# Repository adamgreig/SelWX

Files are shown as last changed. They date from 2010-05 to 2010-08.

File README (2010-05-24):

SelWX

A weather station in Selwyn College, Cambridge, UK.

Reads weather data from a wind vane, anemometer, rain cup, light sensor,
relative humidity sensor, light sensor, temperature sensor and barometric
pressure sensor. Sends this data to a web application over ethernet and
the internet at large.

By Jon Sowman & Adam Greig
May 2010

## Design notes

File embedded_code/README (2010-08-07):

SelWX Embedded Code
This is the code that runs on the ARM in the weather station.

Build requirements are GCC for arm-none-eabi and libopenstm32;
the easiest way to obtain both is via summon-arm-toolchain:
http://github.com/esden/summon-arm-toolchain

Edit it to set LIBOPENSTM32_EN=1 and run, then make sure its resulting
directory (~/arm-none-eabi by default) is in your PATH.

Build with 'make'; 'make upload' will run stm32loader.py to flash the
resulting binary onto the STM32 via its serial bootloader.

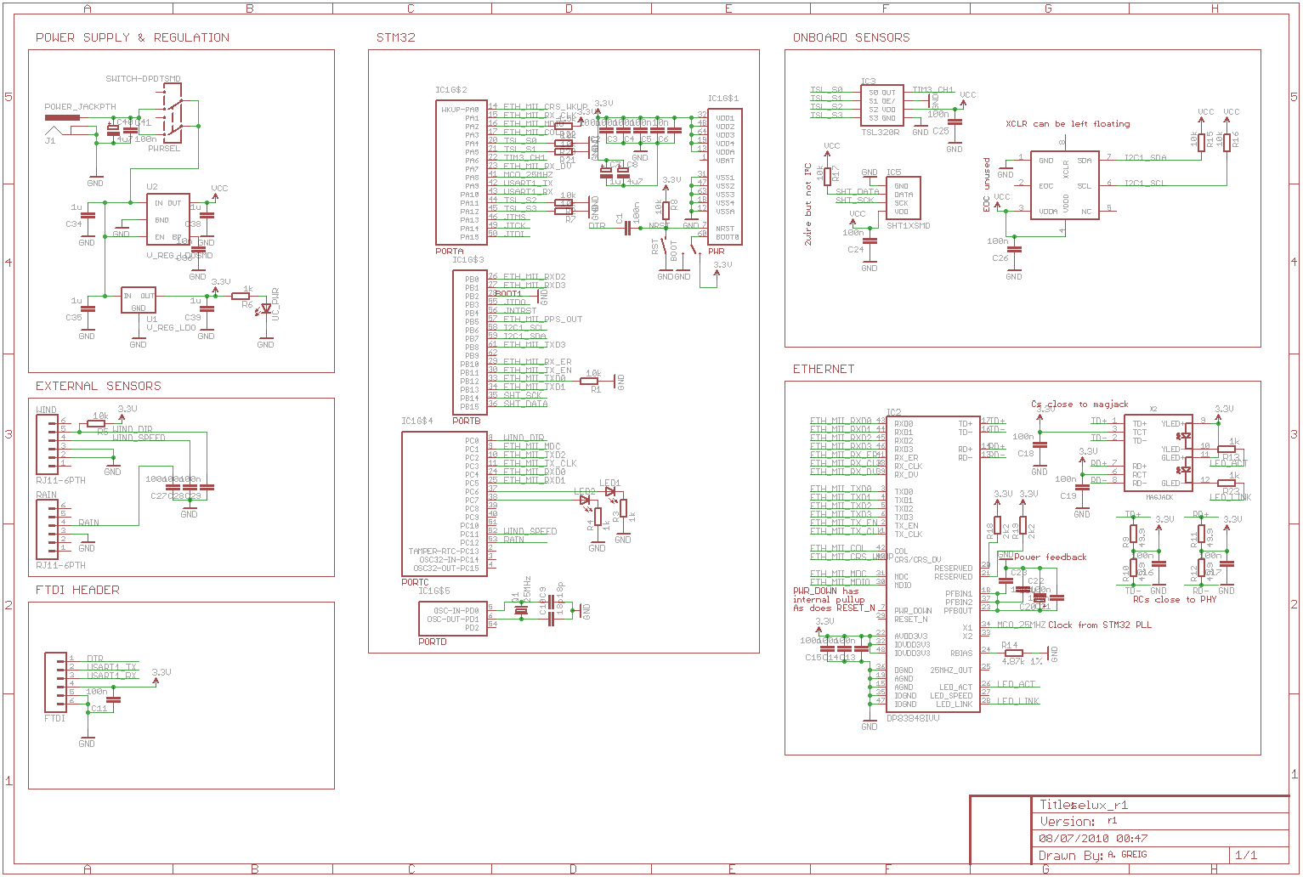
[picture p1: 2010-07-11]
pcb/selwx_r1/selwx_r1_schematic.png

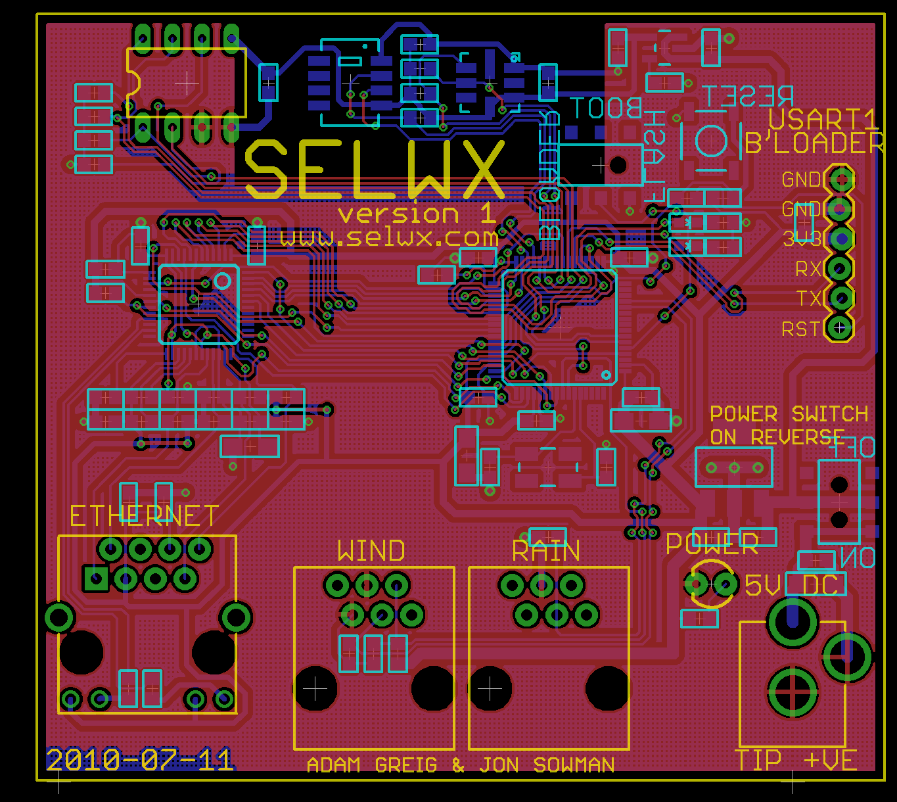
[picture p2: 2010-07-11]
pcb/selwx_r1/selwx_r1_board.png

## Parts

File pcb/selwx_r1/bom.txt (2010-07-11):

Partlist

Exported from selwx_r1.sch at 11/07/2010 18:55

EAGLE Version 5.10.0 Copyright (c) 1988-2010 CadSoft

Part     Value          Device                Package            Library     Sheet

BOOT                    SWITCH-SPSTSMD        AYZ0202            SparkFun    1
C1       100n           C-EUC0603             C0603              rcl         1
C2       100n           C-EUC0603             C0603              rcl         1
C3       100n           C-EUC0603             C0603              rcl         1
C4       100n           C-EUC0603             C0603              rcl         1
C5       100n           C-EUC0603             C0603              rcl         1
C6       10n            C-EUC0603             C0603              rcl         1
C7       1u             CPOL-EUSMCA           SMC_A              rcl         1
C8       4u7            CPOL-EUSMCA           SMC_A              rcl         1
C9       18p            C-EUC0603             C0603              rcl         1
C10      18p            C-EUC0603             C0603              rcl         1
C11      100n           C-EUC0603             C0603              rcl         1
C13      100n           C-EUC0603             C0603              rcl         1
C14      100n           C-EUC0603             C0603              rcl         1
C15      100n           C-EUC0603             C0603              rcl         1
C16      100n           C-EUC0603             C0603              rcl         1
C17      100n           C-EUC0603             C0603              rcl         1
C18      100n           C-EUC0603             C0603              rcl         1
C19      100n           C-EUC0603             C0603              rcl         1
C20      10u            CPOL-EUSMCA           SMC_A              rcl         1
C21      100n           C-EUC0603             C0603              rcl         1
C22      100n           C-EUC0603             C0603              rcl         1
C23      100n           C-EUC0603             C0603              rcl         1
C24      100n           C-EUC0603             C0603              rcl         1
C25      100n           C-EUC0603             C0603              rcl         1
C26      100n           C-EUC0603             C0603              rcl         1
C27      100n           C-EUC0603             C0603              rcl         1
C28      100n           C-EUC0603             C0603              rcl         1
C29      100n           C-EUC0603             C0603              rcl         1
C34      1u             C-EUC0603             C0603              rcl         1
C35      1u             C-EUC0603             C0603              rcl         1
C36      10n            C-EUC0603             C0603              rcl         1
C38      1u             C-EUC0603             C0603              rcl         1
C39      1u             C-EUC0603             C0603              rcl         1
C40      4u7            CPOL-EUSMCA           SMC_A              rcl         1
C41      100n           C-EUC0603             C0603              rcl         1
FTDI                    M06SIP_LOCK           1X06-SIP_LOCK      SparkFun    1
IC1      STM32F107RXTX  STM32F107RXTX         LQFP64             selwx_parts 1
IC2      DP83848IVV     DP83848IVV            LQFP48             selwx_parts 1
IC3      TSL320R        TSL320R               DIL08              selwx_parts 1
IC5      SHT1XSMD       SHT1XSMD              SHT1X              SparkFun    1
IC6      BMP085         BMP085                BMP085             SparkFun    1
J1       POWER_JACKPTH  POWER_JACKPTH         POWER_JACK_PTH     SparkFun    1
LED1                    LED0603               LED-0603           SparkFun    1
LED2                    LED0603               LED-0603           SparkFun    1
PWRSEL   SWITCH-DPDTSMD SWITCH-DPDTSMD        AYZ0202            SparkFun    1
Q1       25MHz          CRYSTAL5X3            CRYSTAL-SMD-5X3    SparkFun    1
R1       10k            R-EU_R0603            R0603              rcl         1
R2       10k            R-EU_R0603            R0603              rcl         1
R3       1k             R-EU_R0603            R0603              rcl         1
R4       1k             R-EU_R0603            R0603              rcl         1
R5       10k            R-EU_R0603            R0603              rcl         1
R6       1k             R-EU_R0603            R0603              rcl         1
R7       10k            R-EU_R0603            R0603              rcl         1
R8       10k            R-EU_R0603            R0603              rcl         1
R9       49.9           R-EU_R0603            R0603              rcl         1
R10      49.9           R-EU_R0603            R0603              rcl         1
R11      49.9           R-EU_R0603            R0603              rcl         1
R12      49.9           R-EU_R0603            R0603              rcl         1
R13      1k             R-EU_R0603            R0603              rcl         1
R14      4.87k 1%       R-EU_R0603            R0603              rcl         1
R15      10k            R-EU_R0603            R0603              rcl         1
R16      10k            R-EU_R0603            R0603              rcl         1
R17      10k            R-EU_R0603            R0603              rcl         1
R18      2k2            R-EU_R0603            R0603              rcl         1
R19      2k2            R-EU_R0603            R0603              rcl         1
R20      10k            R-EU_R0603            R0603              rcl         1
R21      10k            R-EU_R0603            R0603              rcl         1
R22      1.5k           R-EU_R0603            R0603              rcl         1
R23      1k             R-EU_R0603            R0603              rcl         1
RAIN     RJ11-6PTH      RJ11-6PTH             RJ11-6             SparkFun    1
RST                     SWITCH-MOMENTARY-2SMD TACTILE_SWITCH_SMD SparkFun    1
U1       V_REG_LDO      V_REG_MIC2920         SOT223             SparkFun    1
U2       V_REG_LDOSMD   V_REG_LDOSMD          SOT23-5            SparkFun    1
UC_PWR                  LED3MM                LED3MM             SparkFun    1
WIND     RJ11-6PTH      RJ11-6PTH             RJ11-6             SparkFun    1
X2       MAGJACK        MAGJACK               MAGJACK            SparkFun    1

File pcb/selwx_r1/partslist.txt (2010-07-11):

SelWX Bill of Materials
Revision 1

FARNELL

Capacitors
23  100nF 0603              1759016 X
2   18pF 0603               1759056
5   1uF SMC_A               1457406
2   4u7 SMC_A               1754083
2   10u SMC_A               1754086

Resistors
4   49.9 0603               1612045
5   1k 0603                 1469740
1   1k5 0603                1653257
2   2k2 0603                1469765
1   4.87k 1% 0603           1353176
10  10k 0603                1469749

Connectors
1   6pin  0.1" header       1022254 X
2   RJ11 jack               1560166 
1   2.1mm DC power          1217037 X

LEDs
2   Red LED 0603            1685094
1   Green LED 3mm           1003375 X

ICs
1   STM32F107RBT6           1737138
1   DP83848IVV              1286817
1   SHT15                   1590512
1   150mA 3v3 vreg sot23    1578370
1   300mA 3v3 vreg sot223   1578379

Crystals
1   25MHz 5x3               1640936

SPARKFUN

Connectors
1   Magjack w/ LEDs         PRT-08534 X

ICs
1   TSL320R                 SEN-08940 X
1   BMP085                  COM-09603

Switches
2   SMT DPDT                COM-00597
1   SMT momentary           COM-08720

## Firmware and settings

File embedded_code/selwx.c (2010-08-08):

/*
 * SelWX
 * Autonomous weather station
 */

#include <libopenstm32/rcc.h>
#include <libopenstm32/gpio.h>

void gpio_setup(void)
{
    // Enable GPIOC peripheral clock
    rcc_peripheral_enable_clock(&RCC_APB2ENR, RCC_APB2ENR_IOPCEN);

    // Set GPIO6 and 7 to outputs (LEDs)
    gpio_set_mode(
        GPIOC,
        GPIO_MODE_OUTPUT_2_MHZ,
        GPIO_CNF_OUTPUT_PUSHPULL,
        GPIO6 | GPIO7
    );

    // Set GPIO11 and 12 to inputs
    gpio_set_mode(
        GPIOC,
        GPIO_MODE_INPUT,
        GPIO_CNF_INPUT_PULL_UPDOWN,
        GPIO11 | GPIO12
    );

    // Set pullup resistors on GPIO11 and 12
    gpio_set(GPIOC, GPIO11 | GPIO12);
}

int main(void)
{
    gpio_setup();

    while (1) {
        // Read the wind speed and rain sensors, then write their
        // status to the LEDs.
        int weather = gpio_get(GPIOC, GPIO11 | GPIO12);

        if(weather & GPIO11)
            gpio_clear(GPIOC, GPIO6);
        else
            gpio_set(GPIOC, GPIO6);

        if(weather & GPIO12)
            gpio_clear(GPIOC, GPIO7);
        else
            gpio_set(GPIOC, GPIO7);
    }

    return 0;
}

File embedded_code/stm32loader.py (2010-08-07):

#!/usr/bin/env python
# -*- coding: utf-8 -*-

# -*- coding: utf-8 -*-
# vim: sw=4:ts=4:si:et:enc=utf-8

# Author: Ivan A-R <ivan@tuxotronic.org>
# Project page: http://tuxotronic.org/wiki/projects/stm32loader
#
# This file is part of stm32loader.
#
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
import sys, getopt
import serial
import time

try:
    from progressbar import *
    usepbar = 1
except:
    usepbar = 0

# Verbose level
QUIET = 20

def mdebug(level, message):
    if(QUIET >= level):
        print >> sys.stderr , message


class CmdException(Exception):
    pass

class CommandInterface:
    def open(self, aport='/dev/ttyUSB0', abaudrate=115200) :
        self.sp = serial.Serial(
            port=aport,
            baudrate=abaudrate,     # baudrate
            bytesize=8,             # number of databits
            parity=serial.PARITY_EVEN,
            stopbits=1,
            xonxoff=0,              # enable software flow control
            rtscts=0,               # disable RTS/CTS flow control
            timeout=5               # set a timeout value, None for waiting forever
        )


    def _wait_for_ask(self, info = ""):
        # wait for ask
        try:
            ask = ord(self.sp.read())
        except:
            raise CmdException("Can't read port or timeout")
        else:
            if ask == 0x79:
                # ACK
                return 1
            else:
                if ask == 0x1F:
                    # NACK
                    raise CmdException("NACK "+info)
                else:
                    # Unknow responce
                    raise CmdException("Unknown response. "+info+": "+hex(ask))


    def reset(self):
        self.sp.setDTR(1)
        time.sleep(0.5)
        self.sp.setDTR(0)
        time.sleep(0.5)

    def initChip(self):
        # Set boot
        self.sp.setRTS(0)
        self.reset()

        self.sp.write("\x7F")       # Syncro
        self.sp.read()
        return self._wait_for_ask("Syncro")

    def releaseChip(self):
        self.sp.setRTS(1)
        self.reset()

    def cmdGeneric(self, cmd):
        self.sp.write(chr(cmd))
        self.sp.write(chr(cmd ^ 0xFF)) # Control byte
        return self._wait_for_ask(hex(cmd))

    def cmdGet(self):
        if self.cmdGeneric(0x00):
            mdebug(10, "*** Get command");
            len = ord(self.sp.read())
            version = ord(self.sp.read())
            mdebug(10, "    Bootloader version: "+hex(version))
            dat = map(lambda c: hex(ord(c)), self.sp.read(len))
            mdebug(10, "    Available commands: "+str(dat))
            self._wait_for_ask("0x00 end")
            return version
        else:
            raise CmdException("Get (0x00) failed")

    def cmdGetVersion(self):
        if self.cmdGeneric(0x01):
            mdebug(10, "*** GetVersion command")
            version = ord(self.sp.read())
            self.sp.read(2)
            self._wait_for_ask("0x01 end")
            mdebug(10, "    Bootloader version: "+hex(version))
            return version
        else:
            raise CmdException("GetVersion (0x01) failed")

    def cmdGetID(self):
        if self.cmdGeneric(0x02):
            mdebug(10, "*** GetID command")
            len = ord(self.sp.read())
            id = self.sp.read(len+1)
            self._wait_for_ask("0x02 end")
            return id
        else:
            raise CmdException("GetID (0x02) failed")


    def _encode_addr(self, addr):
        byte3 = (addr >> 0) & 0xFF
        byte2 = (addr >> 8) & 0xFF
        byte1 = (addr >> 16) & 0xFF
        byte0 = (addr >> 24) & 0xFF
        crc = byte0 ^ byte1 ^ byte2 ^ byte3
        return (chr(byte0) + chr(byte1) + chr(byte2) + chr(byte3) + chr(crc))


    def cmdReadMemory(self, addr, lng):
        assert(lng <= 256)
        if self.cmdGeneric(0x11):
            mdebug(10, "*** ReadMemory command")
            self.sp.write(self._encode_addr(addr))
            self._wait_for_ask("0x11 address failed")
            N = (lng - 1) & 0xFF
            crc = N ^ 0xFF
            self.sp.write(chr(N) + chr(crc))
            self._wait_for_ask("0x11 length failed")
            return map(lambda c: ord(c), self.sp.read(lng))
        else:
            raise CmdException("ReadMemory (0x11) failed")


    def cmdGo(self, addr):
        if self.cmdGeneric(0x21):
            mdebug(10, "*** Go command")
            self.sp.write(self._encode_addr(addr))
            self._wait_for_ask("0x21 go failed")
        else:
            raise CmdException("Go (0x21) failed")


    def cmdWriteMemory(self, addr, data):
        assert(len(data) <= 256)
        if self.cmdGeneric(0x31):
            mdebug(10, "*** Write memory command")
            self.sp.write(self._encode_addr(addr))
            self._wait_for_ask("0x31 address failed")
            #map(lambda c: hex(ord(c)), data)
            lng = (len(data)-1) & 0xFF
            mdebug(10, "    %s bytes to write" % [lng+1]);
            self.sp.write(chr(lng)) # len really
            crc = 0xFF
            for c in data:
                crc = crc ^ c
                self.sp.write(chr(c))
            self.sp.write(chr(crc))
            self._wait_for_ask("0x31 programming failed")
            mdebug(10, "    Write memory done")
        else:
            raise CmdException("Write memory (0x31) failed")


    def cmdEraseMemory(self, sectors = None):
        if self.cmdGeneric(0x43):
            mdebug(10, "*** Erase memory command")
            if sectors is None:
                # Global erase
                self.sp.write(chr(0xFF))
                self.sp.write(chr(0x00))
            else:
                # Sectors erase
                self.sp.write(chr((len(sectors)-1) & 0xFF))
                crc = 0xFF
                for c in sectors:
                    crc = crc ^ c
                    self.sp.write(chr(c))
                self.sp.write(chr(crc))
            self._wait_for_ask("0x43 erasing failed")
            mdebug(10, "    Erase memory done")
        else:
            raise CmdException("Erase memory (0x43) failed")

    def cmdWriteProtect(self, sectors):
        if self.cmdGeneric(0x63):
            mdebug(10, "*** Write protect command")
            self.sp.write(chr((len(sectors)-1) & 0xFF))
            crc = 0xFF
            for c in sectors:
                crc = crc ^ c
                self.sp.write(chr(c))
            self.sp.write(chr(crc))
            self._wait_for_ask("0x63 write protect failed")
            mdebug(10, "    Write protect done")
        else:
            raise CmdException("Write Protect memory (0x63) failed")

    def cmdWriteUnprotect(self):
        if self.cmdGeneric(0x73):
            mdebug(10, "*** Write Unprotect command")
            self._wait_for_ask("0x73 write unprotect failed")
            self._wait_for_ask("0x73 write unprotect 2 failed")
            mdebug(10, "    Write Unprotect done")
        else:
            raise CmdException("Write Unprotect (0x73) failed")
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

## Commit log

2010-05-24 Initial commit. Eagle library with STM32F107 part, ethernet PHY and light sensor plus the latest Sparkfun Eagle library.
2010-05-24 Added skeleton STM32 project build environment
    [flash-bin.cfg, flash-elf.cfg]
2010-05-24 Added schematic with some parts laid down
    [selwx_r1.sch]
2010-05-24 Added a few more bits to schematic
    [selwx_r1.sch]
2010-05-24 Added 25mhz xtal
    [selwx_r1.sch]
2010-05-26 Continued work on schematic
    [selwx_r1.sch]
2010-05-26 Further schematic improvements. Sensors, STM32, PHY/ethernet done, FTDI and power to go
    [selwx_r1.sch]
2010-05-26 Added PNG of schematic
2010-05-26 Added PHY RESERVED pins which must be pulled high, other error fixing
    [selwx_r1.sch]
2010-05-27 schematic 'done', needs lots of checking and improving
    [selwx_r1.sch]
2010-05-27 Updated STM32 part in library to show pin numbers on schematic
    [selwx_r1.sch]
2010-05-27 Added JTAG header for STM32
    [selwx_r1.sch]
2010-05-27 removed redundant comment on ftdi chip
    [selwx_r1.sch]
2010-05-29 Started work on PCB
    [selwx_r1.brd, selwx_r1.sch]
2010-06-26 Part placement for PCB
    [selwx_r1.brd, selwx_r1.sch]
2010-06-30 Rejigged layout to better fit case
    [selwx_r1.brd, selwx_r1.sch]
2010-07-06 fully routed, needs optimisation
    [selwx_r1.brd, selwx_r1.sch]
2010-07-07 Finished routing and checked schematic and board. Just need to optimise routing.
    [selwx_r1.brd, selwx_r1.sch]
2010-07-07 Updated schematic image
2010-07-08 Added unconnected hatched copper fill to bottom side to balance copper levels
    [selwx_r1.brd]
2010-07-11 Further PCB optimisations
    [selwx_r1.brd]
2010-07-11 Further optimisations. Layout provisionally finished.
    [selwx_r1.brd]
2010-07-11 Silkscreen and GERBERs
    [selwx_r1.brd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]
2010-07-11 New drill file is properly aligned
    [selwx_r1.brd]
2010-07-11 added BOM
2010-07-12 Added file to keep track of revision 1 bugs
2010-08-07 Renamed code to embedded_code
    [flash-bin.cfg, flash-elf.cfg]
2010-08-07 Migrated to libopenstm32. Blink test in this commit.
    [flash-bin.cfg, flash-elf.cfg]
2010-08-07 Added summon-arm-toolchain script
2010-08-08 Monitor rain and wind sensors and flash LEDs appropriately

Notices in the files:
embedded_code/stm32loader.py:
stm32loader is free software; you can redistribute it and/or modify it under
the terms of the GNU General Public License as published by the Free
